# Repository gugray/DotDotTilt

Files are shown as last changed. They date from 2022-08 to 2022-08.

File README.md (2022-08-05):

# Dot-Dot-Tilt!

_Matrix display meets motion sensor for fun inertial games_

This repository contains the source code, schematic, PCB and other design files for Dot-Dot-Tilt!, a small motion-controlled device for inertial simulations and games.

Check out the project's Hackaday page at [hackaday.io/project/186687-dot-dot-tilt](https://hackaday.io/project/186687-dot-dot-tilt), or the short video showing it [in action](https://youtu.be/RH-mNLPE31o).

Here's what it looks like from the front, showing a 3D cube that rotates in reaction to tilting:

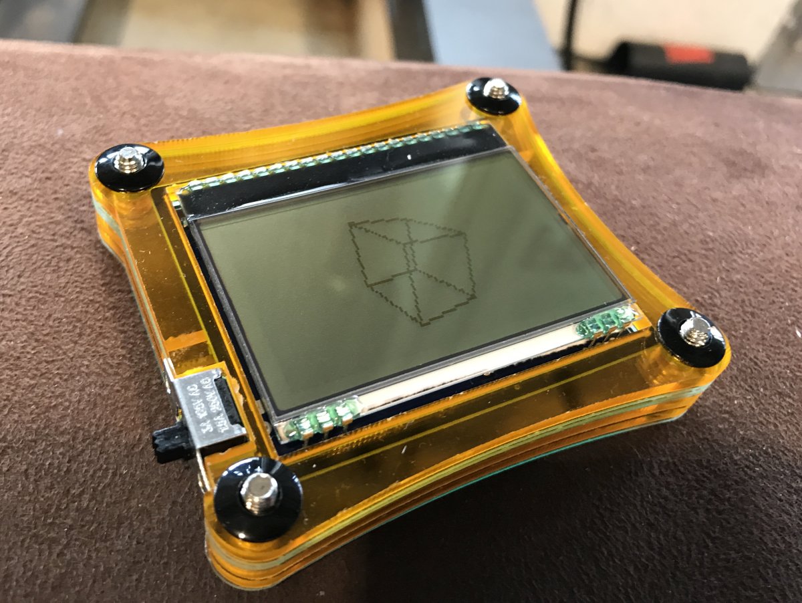
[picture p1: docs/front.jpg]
Front of Dot-Dot-Tilt!


And here's the back view, with the electronics inside:
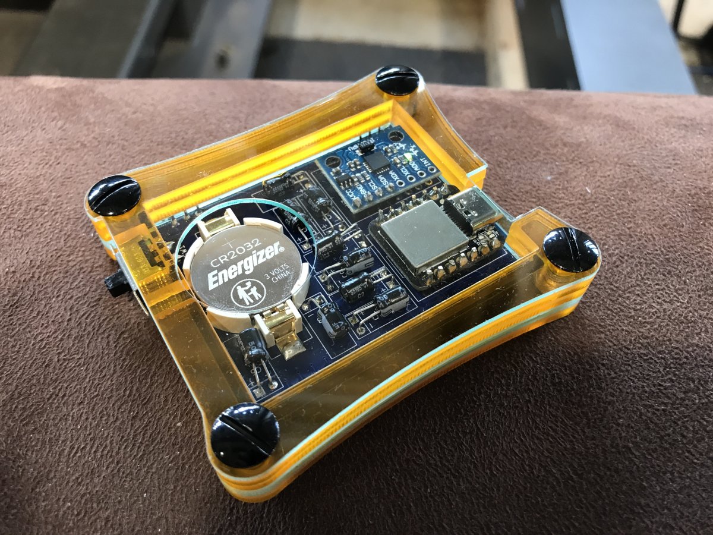
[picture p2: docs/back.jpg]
Back of Dot-Dot-Tilt!


## Building the code

In order to build the C++ source code you need VS Code with the PlatformIO plugin installed. The code here targets the SAMD21 microcontroller, and specifically, the Seeeduino XIAO board.

## License

Everything in this repository, with the exception of the files under `code/lib`, are (C) Gabor L Ugray. All code is released under the MIT license, and all other content is released under Creative Commons CC-BY-SA-NC. The files under `code/lib` are included under their respective licenses, as specified in the source files.

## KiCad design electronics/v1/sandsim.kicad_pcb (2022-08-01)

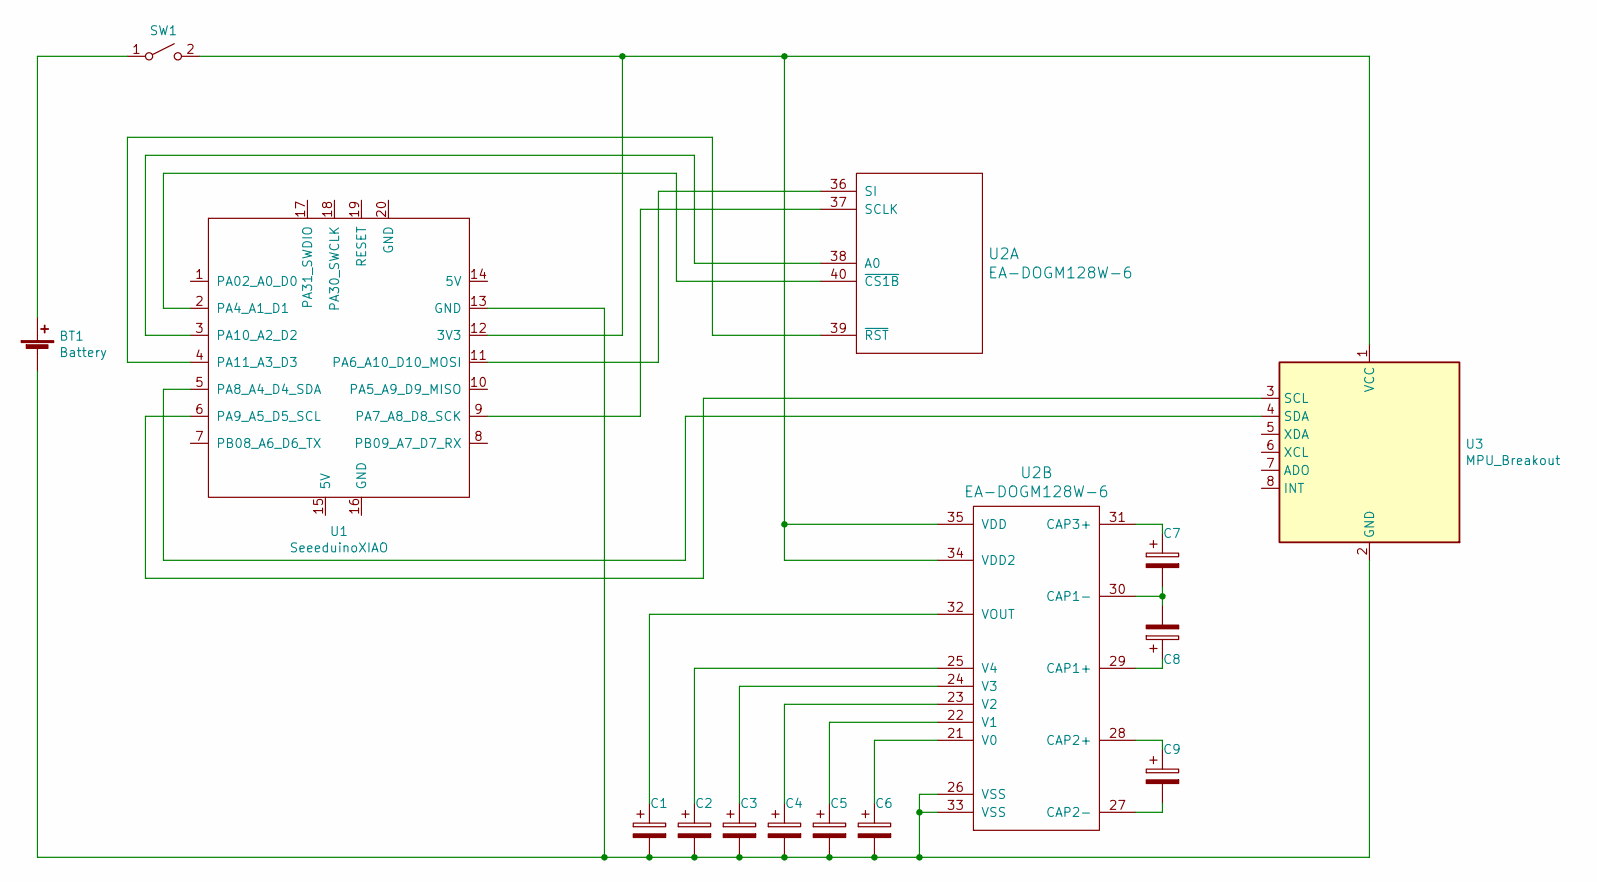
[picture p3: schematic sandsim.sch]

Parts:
BT1: Battery; Battery_CR2032
C1, C2, C3, C4, C5, C6, C7, C8, C9: CP; CP_Radial_D5.0mm_L10mm_P2.50mm_Lying
SW1: SW_SPST; SolderWire-0.25sqmm_1x02_P4.5mm_D0.65mm_OD2mm
U1: SeeeduinoXIAO; XIAO-MOUDLE14P-2.54-21X17.8MM_Pins
U2: EA-DOGM128W-6; EA_DOGM128-6
U3: MPU_Breakout

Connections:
unnamed: BT1.1 (+), SW1.1 (A)
unnamed: BT1.2 (-), C1.2, C2.2, C3.2, C4.2, C5.2, C6.2, U1.13 (GND), U2.26 (VSS), U2.33 (VSS), U3.2 (GND)
unnamed: C1.1, U2.32 (VOUT)
unnamed: C2.1, U2.25 (V4)
unnamed: C3.1, U2.24 (V3)
unnamed: C4.1, U2.23 (V2)
unnamed: C5.1, U2.22 (V1)
unnamed: C6.1, U2.21 (V0)
unnamed: C7.1, U2.31 (CAP3+)
unnamed: C7.2, C8.2, U2.30 (CAP1-)
unnamed: C8.1, U2.29 (CAP1+)
unnamed: C9.1, U2.28 (CAP2+)
unnamed: C9.2, U2.27 (CAP2-)
unnamed: SW1.2 (B), U1.12 (3V3), U2.34 (VDD2), U2.35 (VDD), U3.1 (VCC)
unnamed: U1.2 (PA4_A1_D1), U2.40 (~CS1B)
unnamed: U1.3 (PA10_A2_D2), U2.38 (A0)
unnamed: U1.4 (PA11_A3_D3), U2.39 (~RST)
unnamed: U1.5 (PA8_A4_D4_SDA), U3.4 (SDA)
unnamed: U1.6 (PA9_A5_D5_SCL), U3.3 (SCL)
unnamed: U1.9 (PA7_A8_D8_SCK), U2.37 (SCLK)
unnamed: U1.11 (PA6_A10_D10_MOSI), U2.36 (SI)

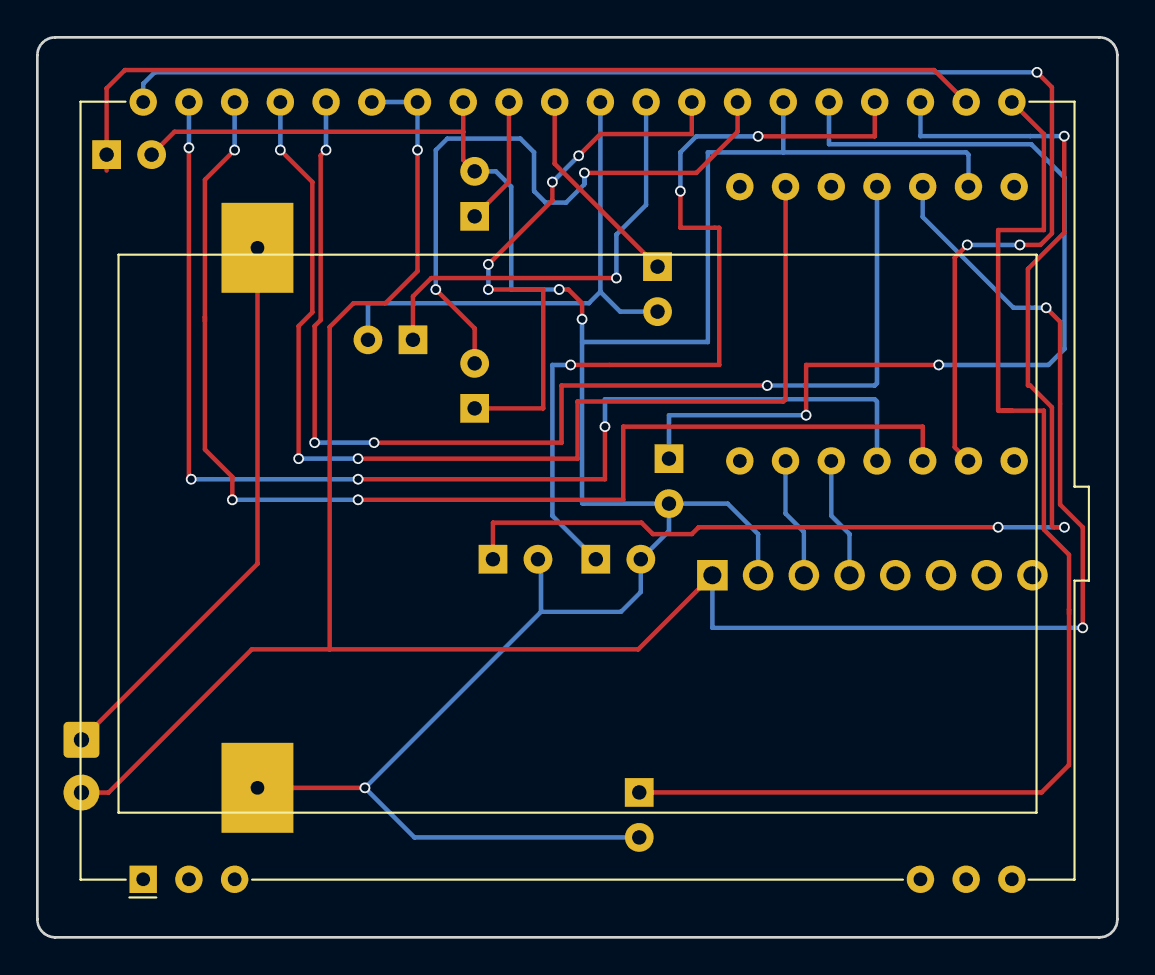
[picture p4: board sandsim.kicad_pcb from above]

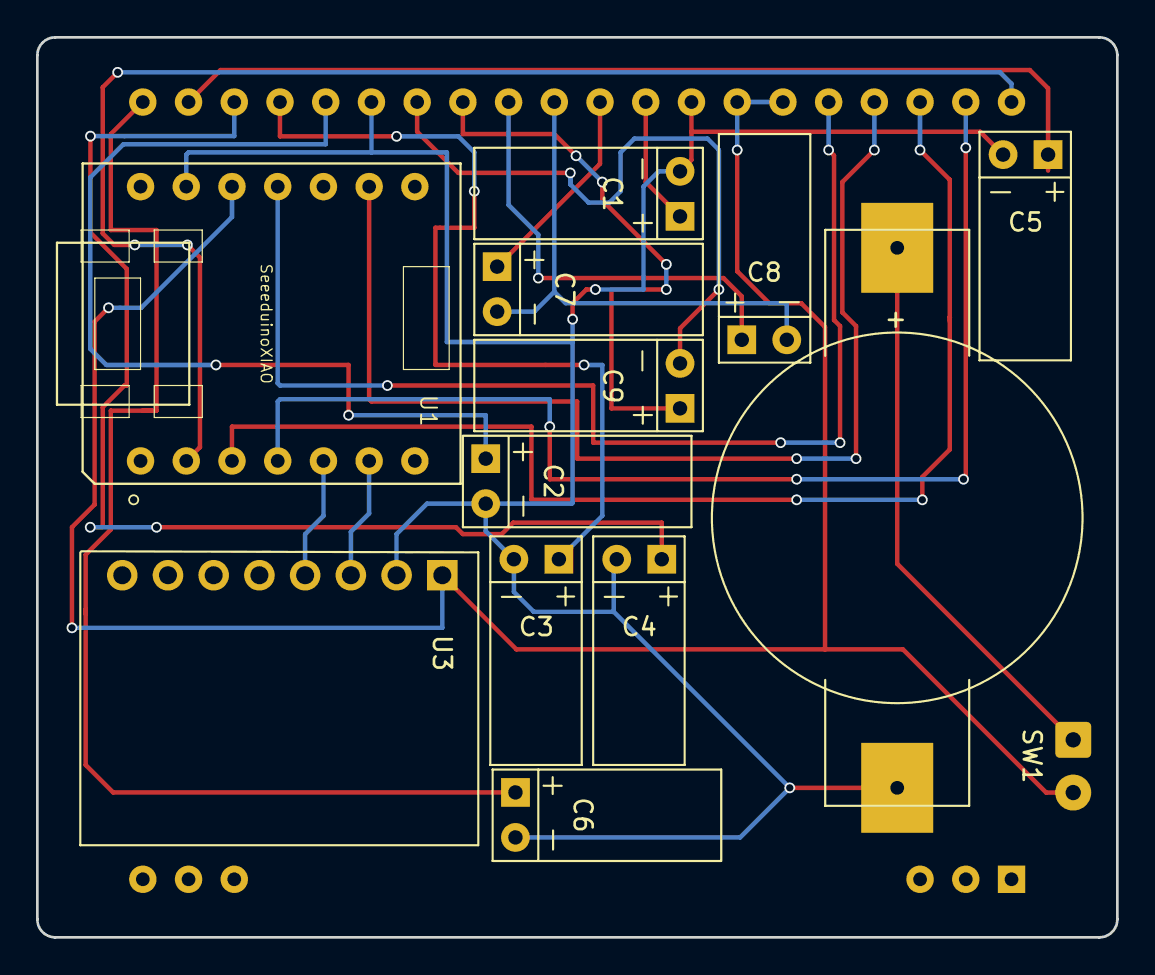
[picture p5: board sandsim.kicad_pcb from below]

Board: 2 copper layers, 60.0 x 50.0 mm, 14 parts (13 on the bottom side), 21 nets.

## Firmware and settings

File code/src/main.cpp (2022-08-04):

#include <Arduino.h>
#pragma GCC diagnostic push
#pragma GCC diagnostic ignored "-Wextra"
#include <SAMDTimerInterrupt.h>
#include <SAMD_ISR_Timer.h>
#pragma GCC diagnostic pop
#include "globals.h"
#include "menu_prog.h"
#include "sand/sand_prog.h"
#include "cube/cube_prog.h"

#define RESET_PIN 3
#define CS_PIN 1
#define A0_PIN 2

#define TIMER_INTERVAL_MS 100
#define HW_TIMER_INTERVAL_MS 50
#define TIMER_INTERVAL_10_MS 10L

bool showFrameMicros = false;
bool progRunning = false;
DOG7565R dog;
MPU6050 mpu(Wire);
Gestures gestures(&mpu);
Canvas canvas;
SAMDTimer ITimer(TIMER_TC3);
SAMD_ISR_Timer ISR_Timer;
char buf[BUF_SZ];
Prog *prog = 0;
Prog *menu = 0;

void flushCanvasToDisplay()
{
  if (!canvas.dirty)
    return;
  canvas.dirty = false;
  uint16_t i = 0;
  for (uint8_t p = 0; p < N_ROWS / 8; ++p)
  {
    dog.position(0, p);
    for (uint8_t x = 0; x < N_COLS; ++x, ++i)
    {
      dog.data(canvas.pixels[i]);
    }
  }
}

void TimerHandler()
{
  ISR_Timer.run();
}

void enterMainMenu()
{
  auto mp = new MenuProg();
  mp->addItem(MenuItem{"Sand", PRG_CODE_SAND});
  mp->addItem(MenuItem{"Cube", PRG_CODE_CUBE});
  menu = mp;
}

void enterQuitMenu()
{
  auto mp = new MenuProg();
  mp->addItem(MenuItem{"Resume", PRG_RESUME});
  mp->addItem(MenuItem{"Quit", PRG_CODE_MENU});
  menu = mp;
}

uint32_t fc = 0;

#pragma GCC diagnostic push
#pragma GCC diagnostic ignored "-Wunused-variable"

void frame()
{
  if (!progRunning)
    return;

  uint32_t tStart = micros();
  mpu.update();

  gestures.frame();

  uint16_t pres = PRG_CONTINUE;
  if (menu != 0)
  {
    pres = menu->frame(fc, gestures.currentGesture());
    if (pres != PRG_CONTINUE)
    {
      delete menu;
      menu = 0;
      if (pres != PRG_RESUME && prog != 0)
      {
        delete prog;
        prog = 0;
      }
      if (pres == PRG_CODE_CUBE)
        prog = new CubeProg();
      else if (pres == PRG_CODE_SAND)
        prog = new SandProg();
      else if (pres == PRG_CODE_MENU)
        enterMainMenu();
    }
  }
  else if (prog != 0)
  {
    if (gestures.currentGesture() == GESTURE_FLIP_LEFT)
      enterQuitMenu();
    else
      pres = prog->frame(fc, gestures.currentGesture());
  }
  if (showFrameMicros)
  {
    uint32_t tEnd = micros();
    sprintf(buf, "%5d usec", (int16_t)(tEnd - tStart));
    canvas.fwText(68, 0, buf);
  }
  flushCanvasToDisplay();
  ++fc;
}

#pragma GCC diagnostic pop

void setup()
{
  // If normal power on: let's reset!
  // Otherwise, MPU is odd an we get no Y angle
  // WTF, but it's what it is.
  if (!PM->RCAUSE.bit.SYST) // Anything but system reset
  {
    __disable_irq();
    NVIC_SystemReset();
    while (true)
      ;
  }

  digitalWrite(PIN_LED, HIGH);
  pinMode(PIN_LED, OUTPUT);

  Serial.begin(115200);

  dog.initialize(CS_PIN, A0_PIN, RESET_PIN, DOGM128);

  Wire.begin();
  mpu.begin(0, 0);

  canvas.fwText(5, 0, "DOT DOT TILT! Hello.");
  canvas.fwText(20, 2, "Please put me on");
  canvas.fwText(20, 3, "a flat surface to");
  canvas.fwText(20, 4, "calibrate");
  flushCanvasToDisplay();
  mpu.calcOffsets();
  mpu.update();

  enterMainMenu();
  // prog = new SandProg();
  // prog = new CubeProg();

  ITimer.attachInterruptInterval_MS(HW_TIMER_INTERVAL_MS, TimerHandler);
  ISR_Timer.setInterval(20, frame);

  canvas.fwText(8 + 11 * 6, 4, ".");
  flushCanvasToDisplay();
  for (uint8_t i = 0; i < 4; ++i)
  {
    delay(500);
    canvas.fwText(8 + (12 + i) * 6, 4, ".");
    flushCanvasToDisplay();
  }

  progRunning = true;
  canvas.clear();
}

void loop()
{
  delay(100);
}

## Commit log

2022-07-15 power saving display refresh: only write on change
2022-08-01 designed board; got working on board; refact for multiple programs
    [sandsim-B_Cu.gbr, sandsim-B_Mask.gbr, sandsim-B_Paste.gbr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]
2022-08-04 we got a menu (with left/right flip gesture)
    [main.cpp]
2022-08-05 update for publishing on hackaday
    [sandsim-B_Cu.gbr, sandsim-B_Mask.gbr, sandsim-B_Paste.gbr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]
